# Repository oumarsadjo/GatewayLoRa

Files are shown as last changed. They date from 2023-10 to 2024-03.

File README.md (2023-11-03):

************************************************
************************************************
*** ANNEE: 2023-2024                         ***
*** PROJET: GetwayLoRa                       ***
*** NIVEAU: 4 annee                          ***
*** ECOLE: Polytch Nice Sophia               ***
*** ELEVES: Oumar Sadjo Barry                ***
***         Mor Djeng                        ***
*** PROFESSEUR: Christian Peter              ***
*** DERNIERE MISE AJOUR: 10/27/2023          ***
************************************************
************************************************

********************************************
*** LES ETAPES QUE NOUS AVONS SUIVI SONT ***
********************************************

1. LECTURES DES DIFFERENTES DOCUMENTATIONS
------------------------------------------
Nous avons commencé par lire attentivement toutes les documents (datasheets),
des deux cartes. C'est qui nous a donne une vue générale de leurs fonctionnements.
Nous avons analysé les differents schematics et prendre connaissance de leur brochages.

2. INTERCONNEXION DES DEUX CARTES (CABLAGE)
------------------------------------------
Apres avoir pris connaissance des deux datasheet, nous avons choisi un protocole de
communication UART pour permettre la transmission. Nous avons identifié l'alimentation
des deux cartes qui à 5V chacune.

3. PROTOCOLE ET BROCHAGE
------------------------
Protocole: UART
Connexion: ESP32 ============> SIM7000G
           5V    ------------> V
           GND   ------------> G
           16    ------------> T //RX to TX
           17    ------------> R //TX to RX

4. UTILISATION DE IDE ARDUINO POUR LES TESTS
--------------------------------------------
Nous avons codé une première fonction "void sendCommand(String myCommand)", qui permet
d'envoyer des commandes AT et afficher le resultat au port serial désiré.
NOTE: Toutes les fonctions sont ecrites dans un fichier d'entete (header), nomme "myFonctions.h".

5. LES PREMIERES FONCTIONS
-------------------------
Nous avons ecris une premiere fonction capable d'envoyer un SMS a un numero désiré nommee : 
"void sendMessage(const char* numero, const char* texte)" et une deuxième fonction qui permet de lire
des messages recus nommee: "void readMessage()".

6. FONCTIONS PRINCIPALES
------------------------
A. void myWiFiConnexion(const char* ssid, const char* password): cette fonction nous permet de se connecter un reseau WiFi desire.

B. void sendRequestByWiFi(const char* ssid, const char* password, const String urlServer):
   Cette fonction permet d'envoyer des requettes HTTP GET en utilisant un reseau WiFi dedié. La limite de cette foncttionnalité,
   est que certains endroits où se projet sera utilisé; n'ont pas de WiFi. Pour aller plus loin, on va utiliser le GSM.
  Elle procede comme suit:
   a. Connexion a un reseau WiFi
   b. Verification de la connexion
   c. Initialisation du protocole HTTP
   d. Obtention de la longeur ou de la taille de la page
   e. Affichage du resultat obtenu
   f. Fermeture du protocole HTTP

C. void sendRequestByGSM(const char* url):
   Cette fonction permet d'envoyer des requettes HTTP GET en utilisant le reseau GSM. L'utilisateur precise le serveur ou le lien.
   Elle procede comme suit:
   a. Initialisation du reseau GSM
   b. Obtention d'une IP adress pour communiquer en GSM
   c. Initialisation du protocole HTTP
   d. Obtention de la longeur ou de la taille de la page
   e. Affichage du resultat obtenu
   f. Fermeture du protocole HTTP

7. ETAPES SCHEMATICS
--------------------
C'est cette etape nous devons commencer maintenant.....

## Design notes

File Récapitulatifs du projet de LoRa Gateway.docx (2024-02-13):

Récapitulatifs du projet de LoRa Gateway

1. Objectif du projet :

Développer un système embarqué utilisant une carte ESP32 pour se connecter à Internet via LoRa, en plus des fonctionnalités WiFi et GSM. Ce système doit pouvoir envoyer des requêtes HTTP pour récupérer des données à partir d'une URL spécifique, ainsi que communiquer via LoRa pour envoyer et recevoir des messages et utiliser des fonctionnalités GPS pour obtenir des informations de localisation.

2. Matériels :

Une carte ESP32 avec prise en charge LoRa, un module carte SIM LTE/GSM, un module GPS, une connexion Internet via WiFi (facultative), une carte SIM, et un ordinateur pour la programmation et le téléversement du code Arduino.

3. Fonctionnement du code :

Le code établit des connexions WiFi, GSM et LoRa, envoie des requêtes HTTP pour récupérer des données, envoie et reçoit des SMS via GSM, et utilise des fonctionnalités GPS pour obtenir des informations de localisation. Il est organisé en fonctions modulaires pour différentes tâches. Les tests ont été réalisés avec succès, confirmant le bon fonctionnement du code.

4. Outils utilisés :

L'IDE Arduino pour l'écriture, la compilation et le téléversement du code, la bibliothèque Arduino pour les périphériques ESP32 avec prise en charge LoRa, des bibliothèques tierces pour la communication GSM, et des modules matériels externes tels que le module GPS. GitHub est utilisé pour la gestion de version du code source, et Eagle est utilisé pour le design de la carte.

5. Avancement du projet :

Les tests ont été effectués avec succès, confirmant le bon fonctionnement du code. La phase de conception du schéma de la carte est terminée et le routage avec Eagle a commencé. Cette phase est cruciale pour garantir la fiabilité et les performances du circuit imprimé, en prenant en compte les spécificités de la communication LoRa.

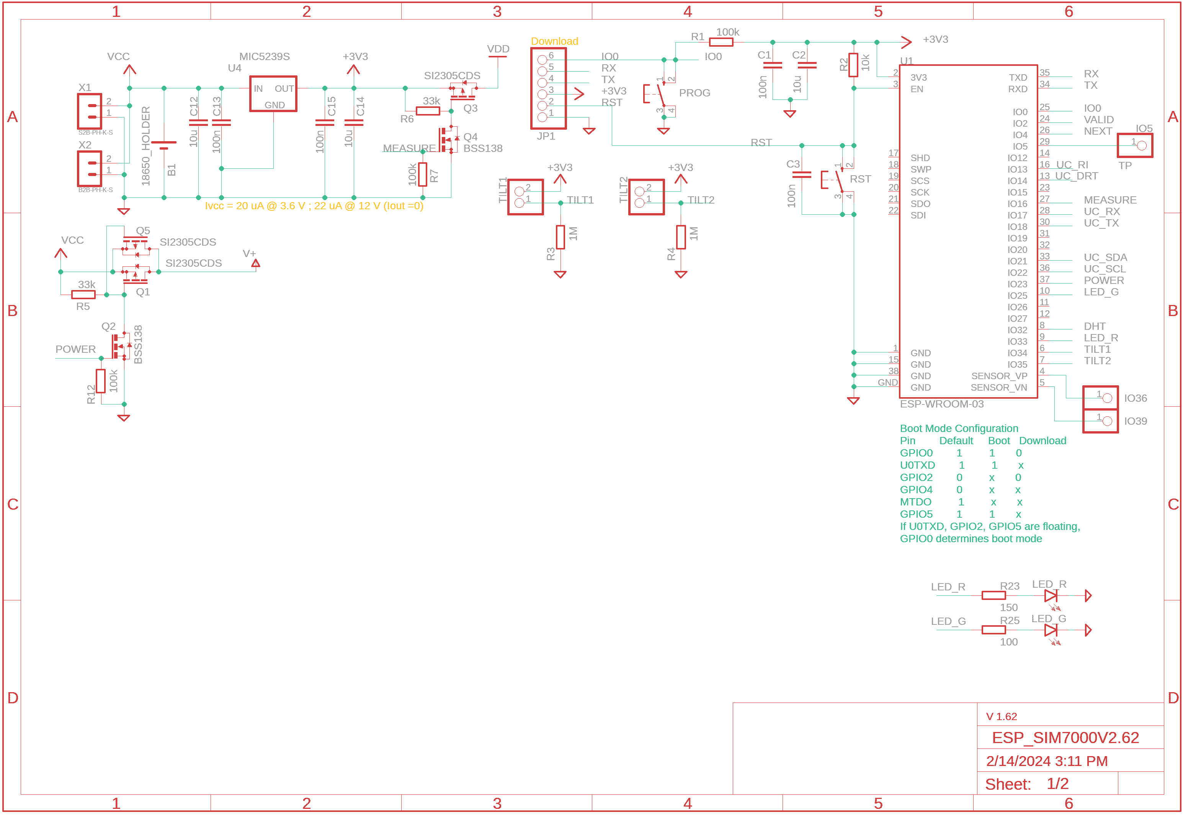
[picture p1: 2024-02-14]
schematic_last_update/Page1.png

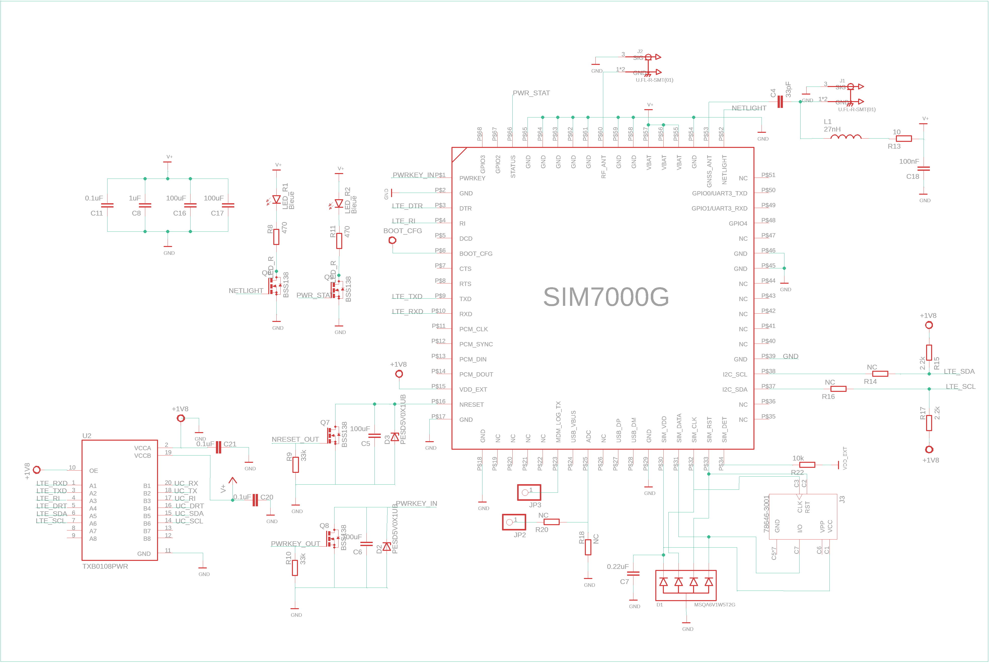
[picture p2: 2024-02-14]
schematic_last_update/Page2.png

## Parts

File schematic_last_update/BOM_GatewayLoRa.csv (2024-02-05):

N� | Type | Part | Value | Device | Package | Needed | Reference | Code commande | SBC | Description | CHECK_PRICES | DESCRIPTION2 | DIGIKEY_PART_NUMBER | MF | MP | MPN | OC_FARNELL | OC_NEWARK | PACKAGE3 | POPULARITY | PRICE | PURCHASE-URL | RS_COMPONENTS_7092778P_PURCHASE_URL | RS_COMPONENTS_7092778_PURCHASE_URL | RS_COMPONENTS_9236790_PURCHASE_URL | SNAPEDA_LINK | SPICEMODEL | SPICEPREFIX | B1 | 18650_HOLDER | C1 | 100n | CC1206 | C1206 | CAPACITOR, European symbol
1 | Diode | D1 | MSQA6V1W5T2G | MSQA6V1W5T2G | SC88A | YES | MSQA6V1W5T2G | 786-2987 | RS | ESD Protection Diode Array Check availability | https://www.snapeda.com/parts/MSQA6V1W5T2G/Onsemi/view-part/?ref=eda | Clamp Ipp Tvs Diode Surface Mount SC-88A (SC-70-5/SOT-353) |  | onsemi | MSQA6V1W5T2G |  |  |  | SC-88A-5 ON Semiconductor |  | None | https://www.snapeda.com/api/url_track_click_mouser/?unipart_id=7122110&manufacturer=onsemi∂_name=MSQA6V1W5T2G&search_term=msqa6v1w5t2g |  |  |  | https://www.snapeda.com/parts/MSQA6V1W5T2G/Onsemi/view-part/?ref=snap
2 | Diode | D2 | PESD5V0X1UB | PESD5V0X1UB | SOD523 | YES | PESD5V0X1UB,135 | 509-386 | RS | Ultra low capacitance unidirectional ElectroStatic Discharge (ESD) protection diode in a | https://www.snapeda.com/parts/PESD5V0X1UB/Nexperia/view-part/?ref=eda | 8V (Typ) Clamp 1.5A (8/20µs) Ipp Tvs Diode Surface Mount SOD-523 |  | Nexperia USA | PESD5V0X1UB |  |  |  | SOD-523 NXP Semiconductors |  | None |  |  |  |  | https://www.snapeda.com/parts/PESD5V0X1UB/Nexperia/view-part/?ref=snap
3 | Diode | D3 | PESD5V0X1UB | PESD5V0X1UB | SOD523 | YES | PESD5V0X1UB,135 | 509-386 | RS | Ultra low capacitance unidirectional ElectroStatic Discharge (ESD) protection diode in a | https://www.snapeda.com/parts/PESD5V0X1UB/Nexperia/view-part/?ref=eda | 8V (Typ) Clamp 1.5A (8/20µs) Ipp Tvs Diode Surface Mount SOD-523 |  | Nexperia USA | PESD5V0X1UB |  |  |  | SOD-523 NXP Semiconductors |  | None |  |  |  |  | https://www.snapeda.com/parts/PESD5V0X1UB/Nexperia/view-part/?ref=snap
4 | Inductor | L1 | 27nH | LQM21PN1R0NGRD | LQM21PN1R0NGRD | YES | 7447880127 | 238-9575 | RS
5 | Registor | R13 | 10 | RR1206 | R1206 | YES |  | 812-1782 | RS | RESISTOR, European symbol |  |  |  |  |  |  |  |  |  |  |  |  |  |  |  |  | NONE | R
6 | Regulator | U3 | TXB0104D | TXB0104D | SOIC127P600X175-14N | YES | TXB0104D | 709-2778 | RS |  | https://www.snapeda.com/parts/TXB0104D/Texas+Instruments/view-part/?ref=eda | 4-Bit Bidirectional Voltage-Level Shifter with Auto Direction Sensing and +/-15 kV ESD Protect |  | Texas Instruments | TXB0104D |  |  |  | SOIC-14 Texas Instruments |  |  | https://www.snapeda.com/api/url_track_click_mouser/?unipart_id=44550&manufacturer=Texas Instruments∂_name=TXB0104D&search_term=txb0104 | https://www.snapeda.com/api/url_track_click/https%253A//uk.rs-online.com/web/p/translator-ics/7092778p//%253Futm_campaign%253Dbuynow%2526utm_medium%253Daggreg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 Instruments∂_name=TXB0104D&search_term=txb0104 | https://www.snapeda.com/api/url_track_click/https%253A//uk.rs-online.com/web/p/translator-ics/7092778//%253Futm_campaign%253Dbuynow%2526utm_medium%253Daggrega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 Instruments∂_name=TXB0104D&search_term=txb0104 | https://www.snapeda.com/api/url_track_click/https%253A//uk.rs-online.com/web/p/translator-ics/9236790//%253Futm_campaign%253Dbuynow%2526utm_medium%253Daggrega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 Instruments∂_name=TXB0104D&search_term=txb0104 | https://www.snapeda.com/parts/TXB0104D/Texas+Instruments/view-part/?ref=snap
7 | SIM | U$2 | 78646-3001 | Micro SIM | 78646-3001 | YES | 78646-3001 | 896-7487 | RS
8 | Capacitor | C1 | 100n | CC1206 | C1206 | Available |  |  | RS | CAPACITOR, European symbol |  |  |  |  |  |  |  |  |  |  |  |  |  |  |  |  | NONE | C
9 | Capacitor | C10 | 0.1uF | CC1210 | C1210 | Available |  |  | RS | CAPACITOR, European symbol |  |  |  |  |  |  |  |  |  |  |  |  |  |  |  |  | NONE | C
10 | Capacitor | C11 | 0.1uF | C-EUC0805 | C0805 | Available |  |  | RS | CAPACITOR, European symbol |  |  |  |  |  |  |  |  |  | 88 |  |  |  |  |  |  |  | C
11 | Capacitor | C12 | 10u | CC1210 | C1210 | Available |  |  | RS | CAPACITOR, European symbol |  |  |  |  |  |  |  |  |  |  |  |  |  |  |  |  | NONE | C
12 | Capacitor | C13 | 100n | CC1206 | C1206 | Available |  |  | RS | CAPACITOR, European symbol |  |  |  |  |  |  |  |  |  |  |  |  |  |  |  |  | NONE | C
13 | Capacitor | C14 | 10u | CC1210 | C1210 | Available |  |  | RS | CAPACITOR, European symbol |  |  |  |  |  |  |  |  |  |  |  |  |  |  |  |  | NONE | C
14 | Capacitor | C15 | 100n | CC1206 | C1206 | Available |  |  | RS | CAPACITOR, European symbol |  |  |  |  |  |  |  |  |  |  |  |  |  |  |  |  | NONE | C
15 | Capacitor | C16 | 100uF | C-EUC0805 | C0805 | Available |  |  | RS | CAPACITOR, European symbol |  |  |  |  |  |  |  |  |  | 88 |  |  |  |  |  |  |  | C
16 | Capacitor | C17 | 100uF | C-EUC0805 | C0805 | Available |  |  | RS | CAPACITOR, European symbol |  |  |  |  |  |  |  |  |  | 88 |  |  |  |  |  |  |  | C
17 | Capacitor | C18 | 100nF | C-EUC0805 | C0805 | Available |  |  | RS | CAPACITOR, European symbol |  |  |  |  |  |  |  |  |  | 88 |  |  |  |  |  |  |  | C
18 | Capacitor | C2 | 10u | CC1210 | C1210 | Available |  |  | RS | CAPACITOR, European symbol |  |  |  |  |  |  |  |  |  |  |  |  |  |  |  |  | NONE | C
19 | Capacitor | C3 | 100n | CC1206 | C1206 | Available |  |  | RS | CAPACITOR, European symbol |  |  |  |  |  |  |  |  |  |  |  |  |  |  |  |  | NONE | C
20 | Capacitor | C4 | 33pF | C-EUC0805 | C0805 | Available |  |  | RS | CAPACITOR, European symbol |  |  |  |  |  |  |  |  |  | 88 |  |  |  |  |  |  |  | C
21 | Capacitor | C5 | 100uF | C-EUC0805 | C0805 | Available |  |  | RS | CAPACITOR, European symbol |  |  |  |  |  |  |  |  |  | 88 |  |  |  |  |  |  |  | C
22 | Capacitor | C6 | 100uF | C-EUC0805 | C0805 | Available |  |  | RS | CAPACITOR, European symbol |  |  |  |  |  |  |  |  |  | 88 |  |  |  |  |  |  |  | C
23 | Capacitor | C7 | 0.22uF | C-EUC0805 | C0805 | Available |  |  | RS | CAPACITOR, European symbol |  |  |  |  |  |  |  |  |  | 88 |  |  |  |  |  |  |  | C
24 | Capacitor | C8 | 1uF | C-EUC0805 | C0805 | Available |  |  | RS | CAPACITOR, European symbol |  |  |  |  |  |  |  |  |  | 88 |  |  |  |  |  |  |  | C
25 | Capacitor | C9 | 0.1uF | CC1210 | C1210 | Available |  |  | RS | CAPACITOR, European symbol |  |  |  |  |  |  |  |  |  |  |  |  |  |  |  |  | NONE | C
26 | Connector | IO36 |  | PINHD-1X1 | 1X01 | Available |  |  | RS | PIN HEADER |  |  |  |  |  |  |  |  |  | 64
27 | Connector | IO39 |  | PINHD-1X1 | 1X01 | Available |  |  | RS | PIN HEADER |  |  |  |  |  |  |  |  |  | 64
28 | Connector | IO5 | TP | PINHD-1X1 | 1X01 | Available |  |  | RS | PIN HEADER |  |  |  |  |  |  |  |  |  | 64
29 | Connector | TILT1 |  | PINHD-1X2 | 1X02 | Available |  |  | RS | PIN HEADER |  |  |  |  |  |  |  |  |  | 98
30 | Connector | TILT2 |  | PINHD-1X2 | 1X02 | Available |  |  | RS | PIN HEADER |  |  |  |  |  |  |  |  |  | 98
31 | IC | U$1 | SIM7000G | SIM7000G | SIM7000G | Available |  |  | RS |  | https://www.snapeda.com/parts/SIM7000G/SIMCom/view-part/?ref=eda | 802.15.4 Cat-M, Cat-NB, EDGE, GPRS, LPWA Transceiver Module 850MHz, 900MHz, 1.8GHz, 1.9GHz Antenna Not Included Surface Mount |  | SIMCom Wireless Solutions Limited | SIM7000G |  |  |  | None |  |  | https://www.snapeda.com/api/url_track_click_mouser/?unipart_id=12130268&manufacturer=SIMCom Wireless Solutions Limited∂_name=SIM7000G&search_term=sim7000g |  |  |  | https://www.snapeda.com/parts/SIM7000G/SIMCom/view-part/?ref=snap
32 | Interupteur | PROG |  | 10-XX | B3F-10XX | Available |  |  | RS | OMRON SWITCH |  |  |  |  |  | B3F-1000 | 176432 | 36M3542 |  | 72
33 | Interupteur | RST |  | 10-XX | B3F-10XX | Available |  |  | RS | OMRON SWITCH |  |  |  |  |  | B3F-1000 | 176432 | 36M3542 |  | 72
34 | LED | LED_G |  | LEDSMT1206 | 1206 | Available |  |  | RS | LED |  |  |  |  |  |  |  |  |  | 20
35 | LED | LED_R |  | LEDSMT1206 | 1206 | Available |  |  | RS | LED |  |  |  |  |  |  |  |  |  | 20
36 | LED | LED_R1 | Bleue | LEDSMT1206 | 1206 | Available |  |  | RS | LED |  |  |  |  |  |  |  |  |  | 20
37 | LED | LED_R2 | Bleue | LEDSMT1206 | 1206 | Available |  |  | RS | LED |  |  |  |  |  |  |  |  |  | 20
38 | Microcontroller | U1 | ESP-WROOM-03 | ESP-WROOM-03 | ESP-WROOM-03 | Available |  |  | RS |  |  |  |  |  |  |  | unknown
39 | Pin Header | JP1 |  | PINHD-1X6 | 1X06 | Available |  |  | RS | PIN HEADER |  |  |  |  |  |  |  |  |  | 79
40 | Pin Header | X1 | S2B-PH-K-S | S2B-PH-K-S | S2B-PH-K-S | Available |  |  | RS | JST PH series header 2.00mm pitch disconnectable crimp style connectors, horizontal (side entry type), 2 pins
41 | Pin Header | X2 | B2B-PH-K-S | B2B-PH-K-S | B2B-PH-K-S | Available |  |  | RS | JST PH series header 2.00mm pitch disconnectable crimp style connectors, vertical (side entry type), 2 pins
42 | Registor | R1 | 100k | RR1206 | R1206 | Available |  |  | RS | RESISTOR, European symbol |  |  |  |  |  |  |  |  |  |  |  |  |  |  |  |  | NONE | R
43 | Registor | R10 | 33k | RR1206 | R1206 | Available |  |  | RS | RESISTOR, European symbol |  |  |  |  |  |  |  |  |  |  |  |  |  |  |  |  | NONE | R
44 | Registor | R11 | 470 | RR1206 | R1206 | Available |  |  | RS | RESISTOR, European symbol |  |  |  |  |  |  |  |  |  |  |  |  |  |  |  |  | NONE | R
45 | Registor | R12 | 100k | RR1206 | R1206 | Available |  |  | RS | RESISTOR, European symbol |  |  |  |  |  |  |  |  |  |  |  |  |  |  |  |  | NONE | R
46 | Registor | R14 | NC | RR1206 | R1206 | Available |  |  | RS | RESISTOR, European symbol |  |  |  |  |  |  |  |  |  |  |  |  |  |  |  |  | NONE | R
47 | Registor | R15 | 2.2k | RR1206 | R1206 | Available |  |  | RS | RESISTOR, European symbol |  |  |  |  |  |  |  |  |  |  |  |  |  |  |  |  | NONE | R
48 | Registor | R16 | NC | RR1206 | R1206 | Available |  |  | RS | RESISTOR, European symbol |  |  |  |  |  |  |  |  |  |  |  |  |  |  |  |  | NONE | R
49 | Registor | R17 | 2.2k | RR1206 | R1206 | Available |  |  | RS | RESISTOR, European symbol |  |  |  |  |  |  |  |  |  |  |  |  |  |  |  |  | NONE | R
50 | Registor | R2 | 10k | RR1206 | R1206 | Available |  |  | RS | RESISTOR, European symbol |  |  |  |  |  |  |  |  |  |  |  |  |  |  |  |  | NONE | R
51 | Registor | R23 | 150 | RR1206 | R1206 | Available |  |  | RS | RESISTOR, European symbol |  |  |  |  |  |  |  |  |  |  |  |  |  |  |  |  | NONE | R
52 | Registor | R25 | 100 | RR1206 | R1206 | Available |  |  | RS | RESISTOR, European symbol |  |  |  |  |  |  |  |  |  |  |  |  |  |  |  |  | NONE | R
53 | Registor | R3 | 1M | RR1206 | R1206 | Available |  |  | RS | RESISTOR, European symbol |  |  |  |  |  |  |  |  |  |  |  |  |  |  |  |  | NONE | R
54 | Registor | R4 | 1M | RR1206 | R1206 | Available |  |  | RS | RESISTOR, European symbol |  |  |  |  |  |  |  |  |  |  |  |  |  |  |  |  | NONE | R
55 | Registor | R5 | 33k | RR1206 | R1206 | Available |  |  | RS | RESISTOR, European symbol |  |  |  |  |  |  |  |  |  |  |  |  |  |  |  |  | NONE | R
56 | Registor | R6 | 33k | RR1206 | R1206 | Available |  |  | RS | RESISTOR, European symbol |  |  |  |  |  |  |  |  |  |  |  |  |  |  |  |  | NONE | R
57 | Registor | R7 | 100k | RR1206 | R1206 | Available |  |  | RS | RESISTOR, European symbol |  |  |  |  |  |  |  |  |  |  |  |  |  |  |  |  | NONE | R
58 | Registor | R8 | 470 | RR1206 | R1206 | Available |  |  | RS | RESISTOR, European symbol |  |  |  |  |  |  |  |  |  |  |  |  |  |  |  |  | NONE | R
59 | Registor | R9 | 33k | RR1206 | R1206 | Available |  |  | RS | RESISTOR, European symbol |  |  |  |  |  |  |  |  |  |  |  |  |  |  |  |  | NONE | R
60 | Regulator | U4 | MIC5239S | MIC5239S | SOT223 | Available |  |  | RS | LDO REGULATOR
61 | Transistor | Q1 | SI2305CDS | SI2305CDS | SOT23 | Available |  |  | RS | P-CHANNEL MOS FET
62 | Transistor | Q2 | BSS138 | BSS131 | SOT23 | Available |  |  | RS | N-CHANNEL MOS FET
63 | Transistor | Q3 | SI2305CDS | SI2305CDS | SOT23 | Available |  |  | RS | P-CHANNEL MOS FET
64 | Transistor | Q4 | BSS131 | BSS131 | SOT23 | Available |  |  | RS | N-CHANNEL MOS FET
65 | Transistor | Q5 | SI2305CDS | SI2305CDS | SOT23 | Available |  |  | RS | P-CHANNEL MOS FET
66 | Transistor | Q6 | BSS138 | BSS131 | SOT23 | Available |  |  | RS | N-CHANNEL MOS FET
67 | Transistor | Q7 | BSS138 | BSS131 | SOT23 | Available |  |  | RS | N-CHANNEL MOS FET
68 | Transistor | Q8 | BSS138 | BSS131 | SOT23 | Available |  |  | RS | N-CHANNEL MOS FET
69 | Transistor | Q9 | BSS138 | BSS131 | SOT23 | Available |  |  | RS | N-CHANNEL MOS FET
70 | UFL | J1 | U.FL-R-SMT(01) | U.FL-R-SMT(01) | HRS_U.FL-R-SMT(01) | Available |  |  | RS | U.FL Series 6 Ghz 50 Ohm Ultra-small SMT Coaxial Cable Receptacle Check availability | https://www.snapeda.com/parts/U.FL-R-SMT(01)/Hirose+Electric+Co+Ltd/view-part/?ref=eda | U.FL (UMCC) Connector Receptacle, Male Pin 50Ohm Surface Mount Solder. RF Connectors / Coaxial Connectors |  | Hirose | U.FL-R-SMT(01) |  |  |  | None |  | None | https://www.snapeda.com/api/url_track_click_mouser/?unipart_id=49572&manufacturer=Hirose∂_name=U.FL-R-SMT(01)&search_term=None |  |  |  | https://www.snapeda.com/parts/U.FL-R-SMT(01)/Hirose+Electric+Co+Ltd/view-part/?ref=snap
71 | UFL | J2 | U.FL-R-SMT(01) | U.FL-R-SMT(01) | HRS_U.FL-R-SMT(01) | Available |  |  | RS | U.FL Series 6 Ghz 50 Ohm Ultra-small SMT Coaxial Cable Receptacle Check availability | https://www.snapeda.com/parts/U.FL-R-SMT(01)/Hirose+Electric+Co+Ltd/view-part/?ref=eda | U.FL (UMCC) Connector Receptacle, Male Pin 50Ohm Surface Mount Solder. RF Connectors / Coaxial Connectors |  | Hirose | U.FL-R-SMT(01) |  |  |  | None |  | None | https://www.snapeda.com/api/url_track_click_mouser/?unipart_id=49572&manufacturer=Hirose∂_name=U.FL-R-SMT(01)&search_term=None |  |  |  | https://www.snapeda.com/parts/U.FL-R-SMT(01)/Hirose+Electric+Co+Ltd/view-part/?ref=snap
72 |  | B1 | 18650_HOLDER | 18650_HOLDER | 18650 | Available |  |  | RS | 18650 holder
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

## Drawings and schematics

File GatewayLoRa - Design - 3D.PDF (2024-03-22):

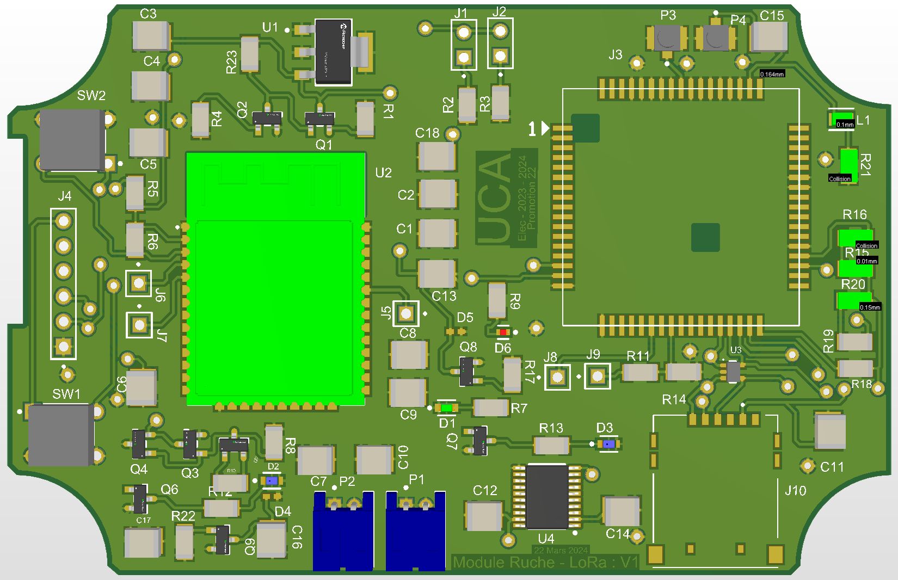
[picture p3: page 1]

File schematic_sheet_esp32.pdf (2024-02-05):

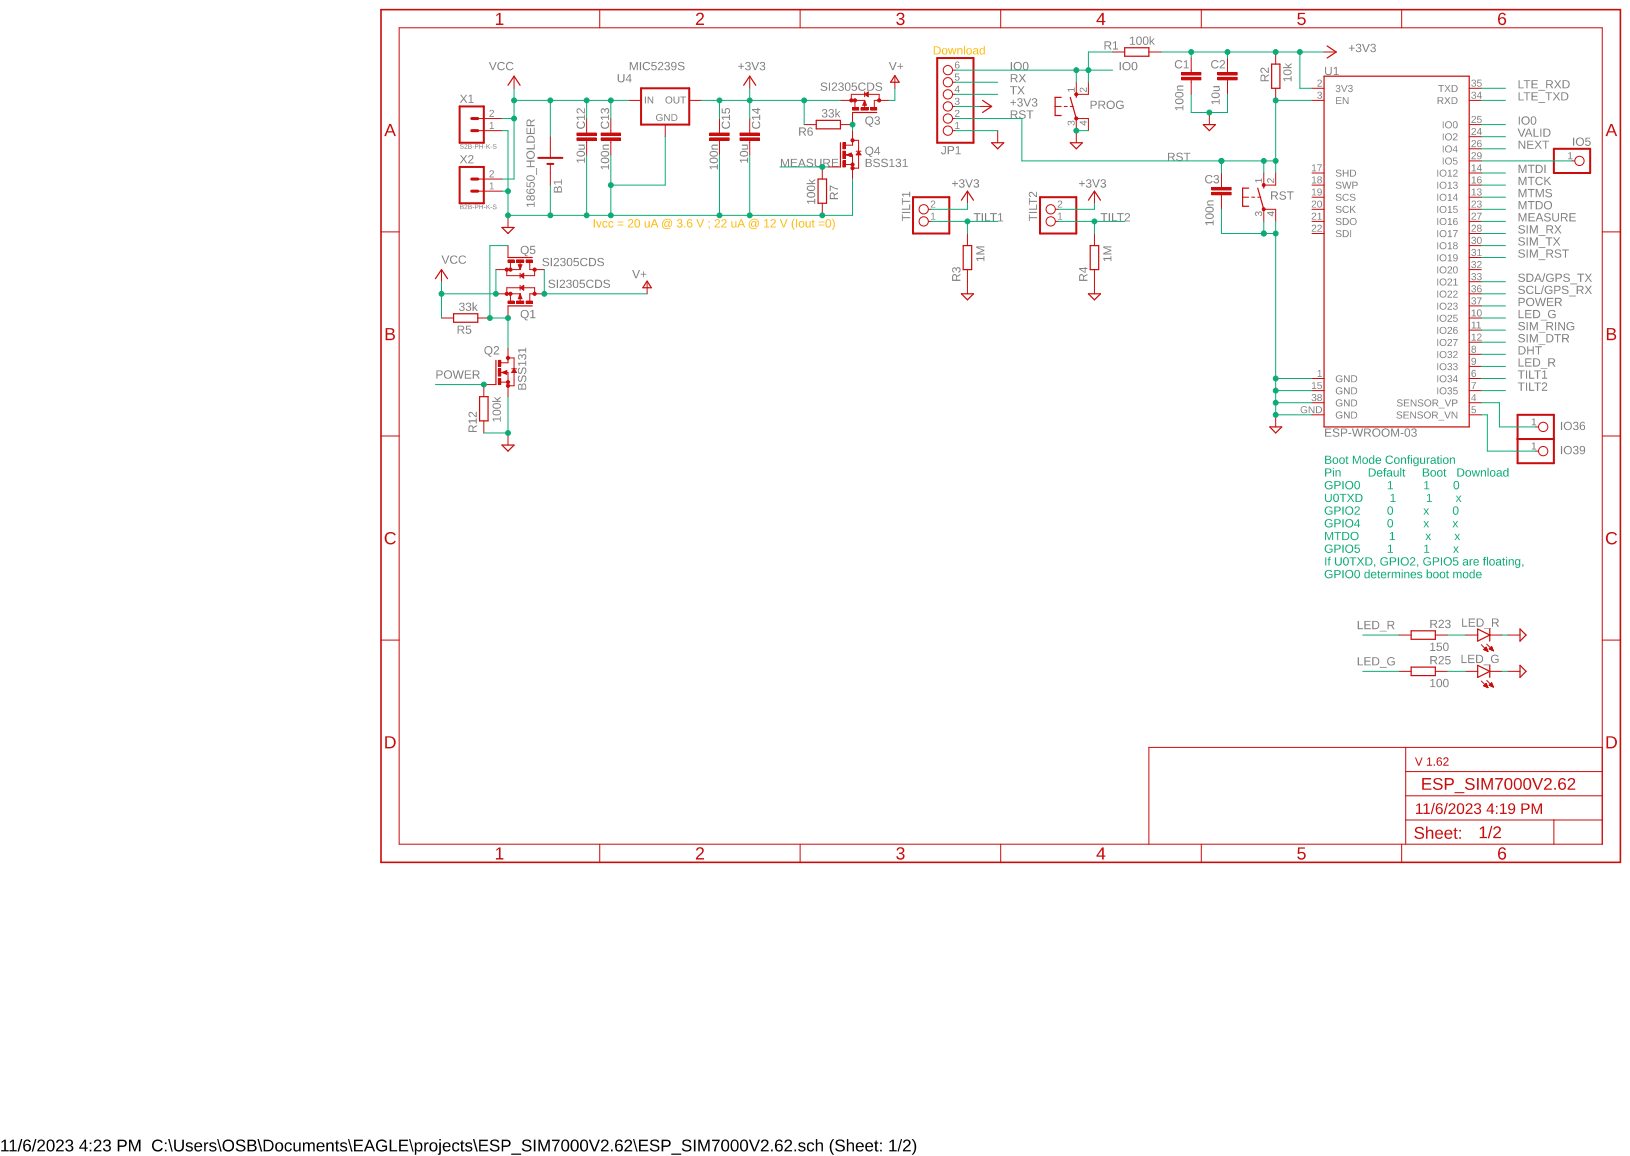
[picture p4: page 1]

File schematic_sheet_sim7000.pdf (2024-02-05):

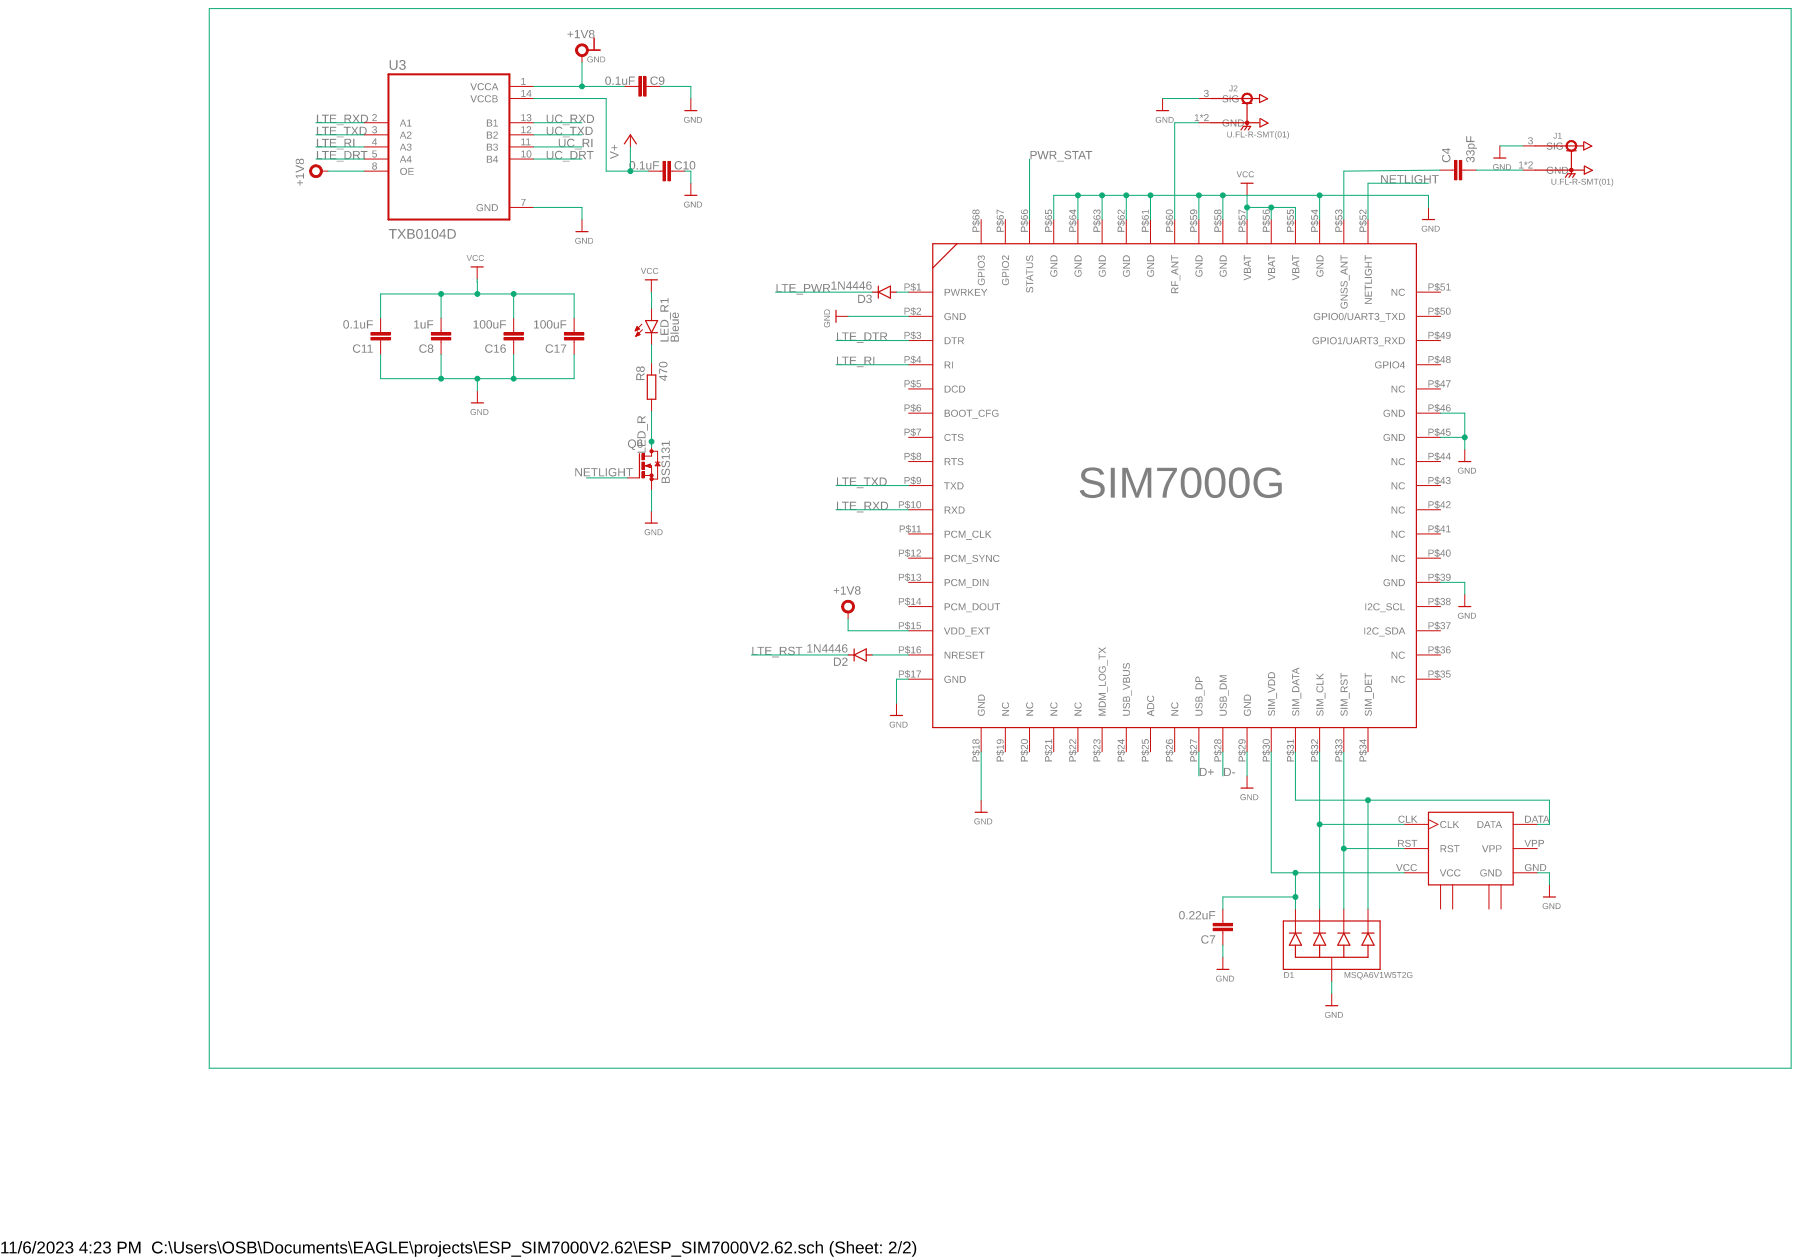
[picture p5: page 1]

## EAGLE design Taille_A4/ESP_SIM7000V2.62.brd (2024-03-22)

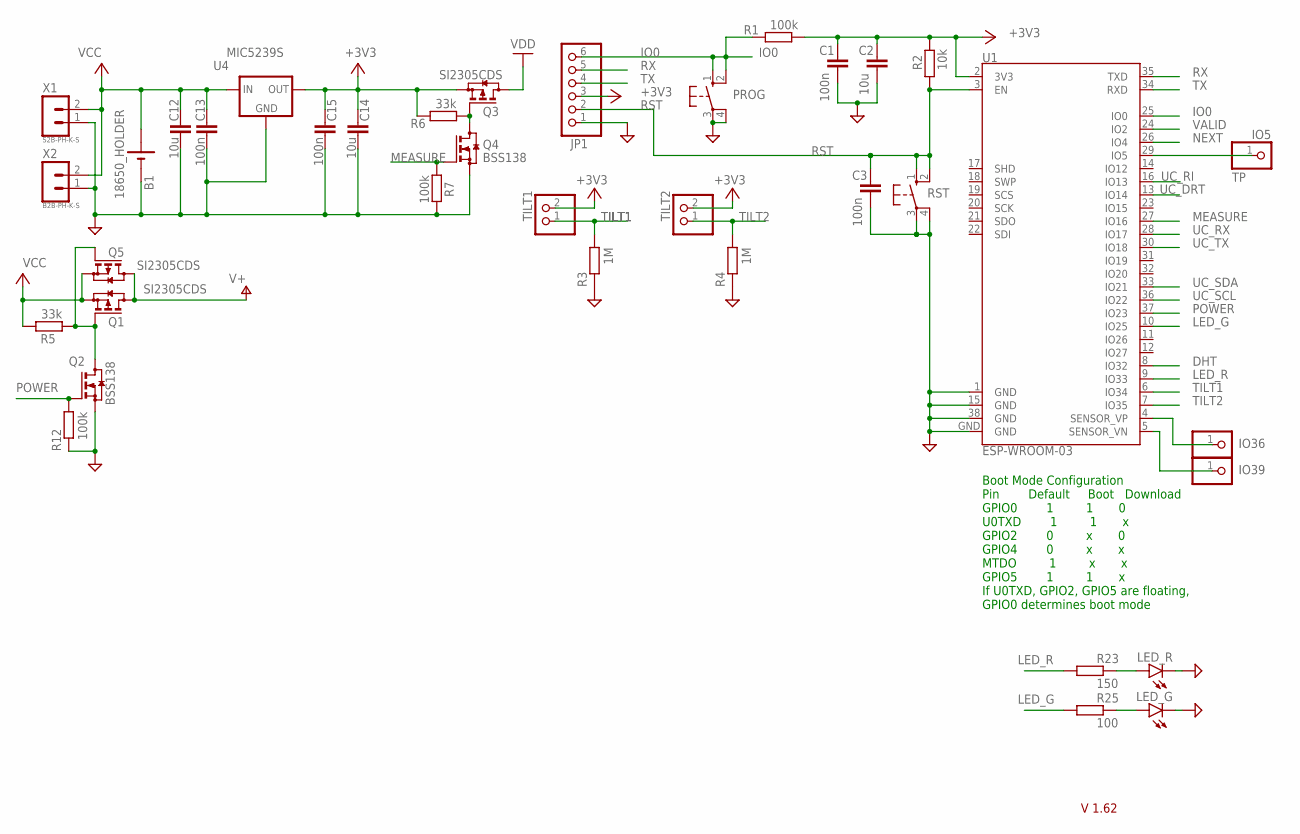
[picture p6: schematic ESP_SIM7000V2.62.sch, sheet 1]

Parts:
B1: 18650_HOLDER; 18650
C1, C3, C13, C15: 100n; C1206
C2, C12, C14: 10u; C1210
IO5: TP; 1X01
IO36, IO39: PINHD-1X1; 1X01
JP1: PINHD-1X6; 1X06
LED_G: LEDSMT1206; 1206
LED_R: LEDSMT1206; 1206
PROG: 10-XX; B3F-10XX
Q1, Q3, Q5: SI2305CDS; SOT23
Q2, Q4: BSS138; SOT23
R1, R7, R12: 100k; R1206
R2: 10k; R1206
R3, R4: 1M; R1206
R5, R6: 33k; R1206
R23: 150; R1206
R25: 100; R1206
RST: 10-XX; B3F-10XX
TILT1, TILT2: PINHD-1X2; 1X02
U1: ESP-WROOM-03
U4: MIC5239S; SOT223
X1: S2B-PH-K-S
X2: B2B-PH-K-S

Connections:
+3V3: C1.1, C2.1, C14.1, C15.1, JP1.3, Q3.2 (S), R1.1, R2.2, R6.2, TILT1.2, TILT2.2, U1.2 (3V3), U4.3 (OUT)
DHT: U1.8 (IO32)
GND: B1.-, C1.2, C2.2, C3.2, C12.2, C13.2, C14.2, C15.2, JP1.1, LED_G.C, LED_R.C, PROG.3, PROG.4 (P1), Q2.2 (S), Q4.2 (S), R3.2, R4.2, R7.2, R12.2, RST.3, RST.4 (P1), U1.1 (GND), U1.15 (GND), U1.38 (GND), U1.GND, U4.2 (GND), U4.4 (GND), X1.1, X2.1; also elsewhere on the board
IO0: JP1.6, PROG.1 (S), PROG.2 (S1), R1.2, U1.25 (IO0)
IO36: IO36.1, U1.4 (SENSOR_VP)
IO39: IO39.1, U1.5 (SENSOR_VN)
LED_G: R25.1, U1.10 (IO25)
LED_R: R23.1, U1.9 (IO33); also elsewhere on the board
MEASURE: Q4.1 (G), R7.1, U1.27 (IO16)
unnamed: Q1.1 (G), Q2.3 (D), Q5.1 (G), R5.1
unnamed: Q3.1 (G), Q4.3 (D), R6.1
unnamed: LED_R.A, R23.2
unnamed: LED_G.A, R25.2
unnamed: IO5.1, U1.29 (IO5)
NEXT: U1.26 (IO4)
POWER: Q2.1 (G), R12.1, U1.37 (IO23)
RST: C3.1, JP1.2, R2.1, RST.1 (S), RST.2 (S1), U1.3 (EN)
RX: JP1.5, U1.35 (TXD)
TILT1: R3.1, TILT1.1, U1.6 (IO34)
TILT2: R4.1, TILT2.1, U1.7 (IO35)
TX: JP1.4, U1.34 (RXD)
UC_DRT: U1.13 (IO14); also elsewhere on the board
UC_RI: U1.16 (IO13); also elsewhere on the board
UC_RX: U1.28 (IO17); also elsewhere on the board
UC_SCL: U1.36 (IO22); also elsewhere on the board
UC_SDA: U1.33 (IO21); also elsewhere on the board
UC_TX: U1.30 (IO18); also elsewhere on the board
V+: Q1.3 (D), Q5.3 (D)
VALID: U1.24 (IO2)
VCC: B1.+, C12.1, C13.1, Q1.2 (S), Q5.2 (S), R5.2, U4.1 (IN), X1.2, X2.2
VDD: Q3.3 (D)

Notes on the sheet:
Boot Mode Configuration Pin Default Boot Download GPIO0 1 1 0 U0TXD 1 1 x GPIO2 0 x 0 GPIO4 0 x x MTDO 1 x x GPIO5 1 1 x If U0TXD, GPIO2, GPIO5 are floating, GPIO0 determines boot mode
V 1.62

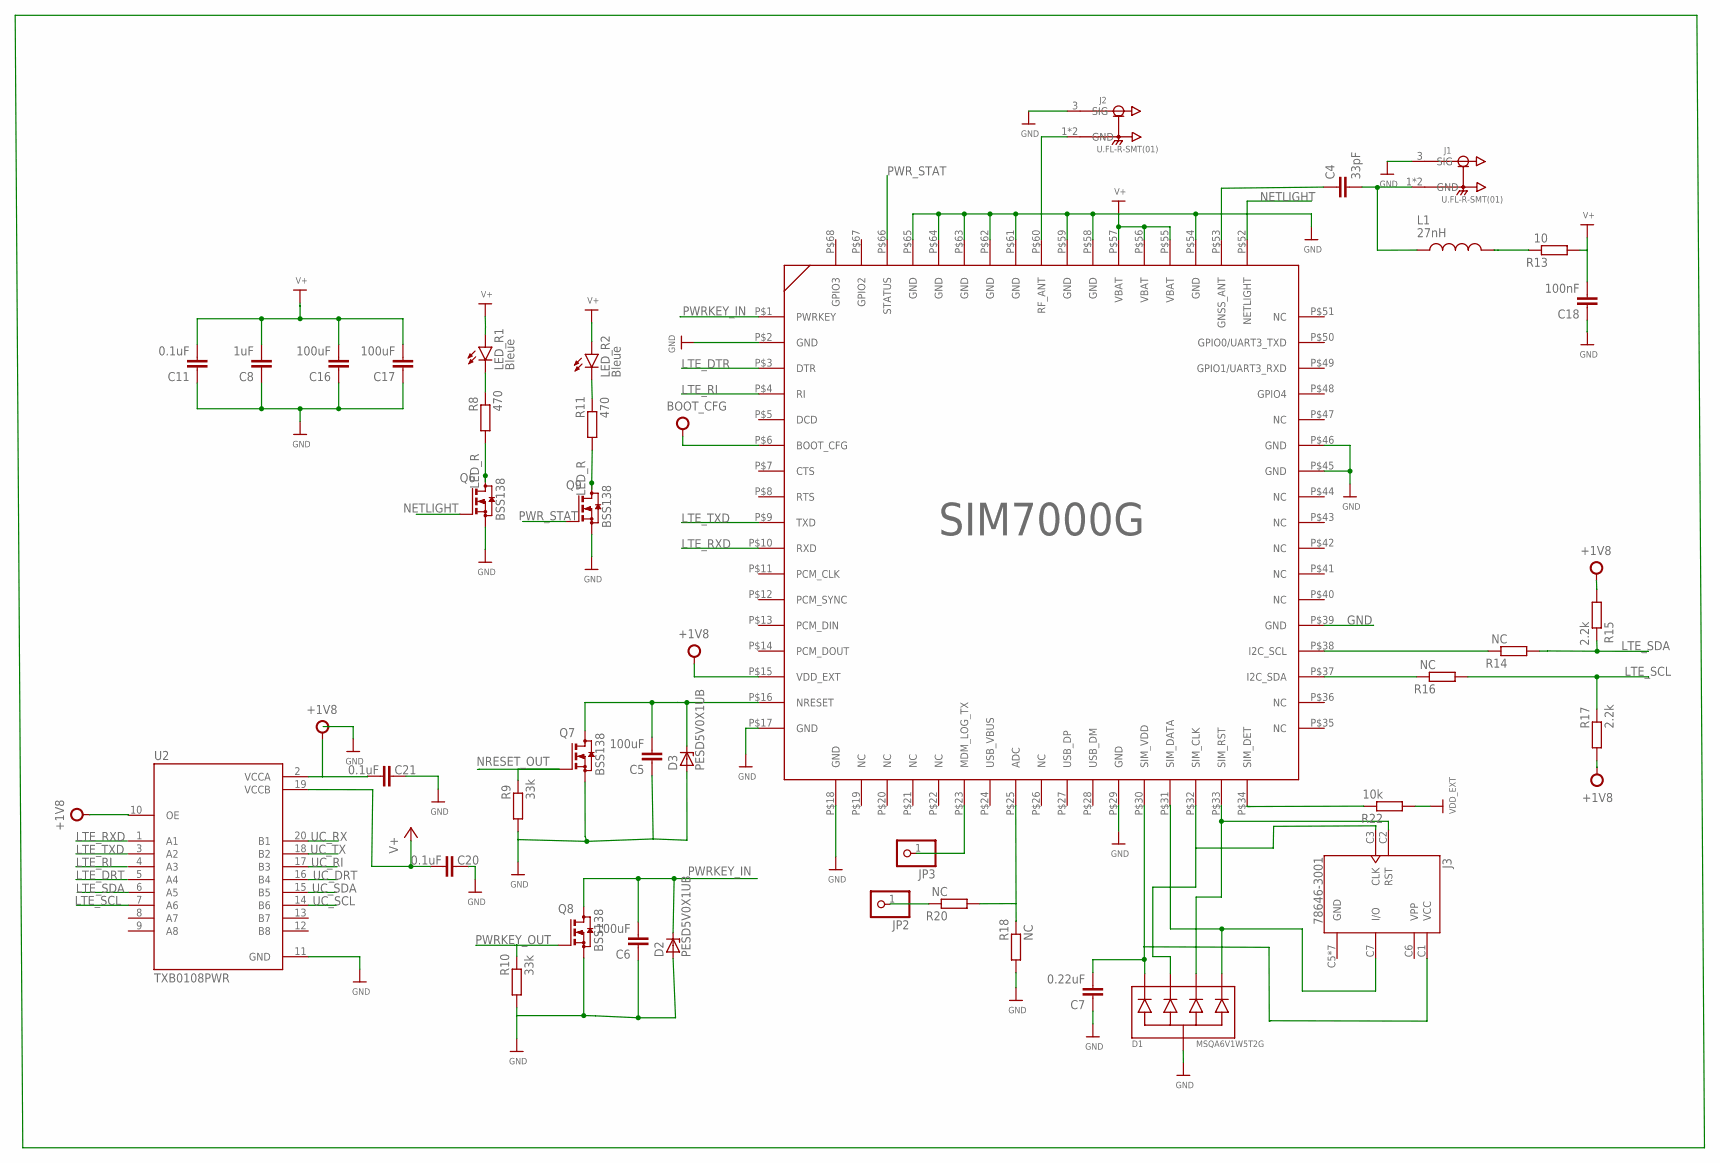
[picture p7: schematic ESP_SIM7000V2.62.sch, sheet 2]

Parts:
C4: 33pF; C0805
C5, C6, C16, C17: 100uF; C0805
C7: 0.22uF; C0805
C8: 1uF; C0805
C11: 0.1uF; C0805
C18: 100nF; C0805
C20, C21: 0.1uF; C1210
D1: MSQA6V1W5T2G; SC88A
D2, D3: PESD5V0X1UB; SOD523
J1, J2: U.FL-R-SMT(01); HRS_U.FL-R-SMT(01)
J3: 78646-3001; MOLEX_78646-3001
JP2, JP3: PINHD-1X1; 1X01
L1: 27nH; INDC2012X100N
LED_R1, LED_R2: Bleue; 1206
Q6, Q7, Q8, Q9: BSS138; SOT23
R8, R11: 470; R1206
R9, R10: 33k; R1206
R13: 10; R1206
R14, R16, R18, R20: NC; R1206
R15, R17: 2.2k; R1206
R22: 10k; R1206
U2: TXB0108PWR; SOP65P640X120-20N
U$1: SIM7000G

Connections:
+1V8: C21.2, R15.1, R17.1, U2.2 (VCCA), U2.10 (OE), U$1.P$6 (BOOT_CFG), U$1.P$15 (VDD_EXT)
+5V: C20.2, U2.19 (VCCB)
GND: C7.1, C8.1, C11.1, C16.1, C17.1, C18.1, C20.1, C21.1, D1.2, J1.3 (SIG), J2.3 (SIG), J3.C5 (GND), J3.G1 (GND), J3.G2 (GND), J3.G3 (GND), J3.G4 (GND), J3.G5 (GND), J3.G6 (GND), LED_R2.A, Q6.2 (S), Q9.2 (S), R18.1, R22.1, U2.11 (GND), U$1.P$2 (GND), U$1.P$17 (GND), U$1.P$18 (GND), U$1.P$29 (GND), U$1.P$39 (GND), U$1.P$45 (GND), U$1.P$46 (GND), U$1.P$54 (GND), U$1.P$55 (VBAT), U$1.P$56 (VBAT), U$1.P$57 (VBAT), U$1.P$58 (GND), U$1.P$59 (GND), U$1.P$61 (GND), U$1.P$62 (GND), U$1.P$63 (GND), U$1.P$64 (GND), U$1.P$65 (GND); also elsewhere on the board
LED_R: Q6.3 (D), Q9.3 (D), R8.1, R11.1; also elsewhere on the board
LTE_DTR: U$1.P$3 (DTR)
LTE_RI: U$1.P$4 (RI)
LTE_RXD: U$1.P$10 (RXD)
LTE_SCL: R16.1, R17.2, U2.7 (A6)
LTE_SDA: R14.1, R15.2, U2.6 (A5)
LTE_TXD: U$1.P$9 (TXD)
unnamed: J2.1 (GND), J2.2 (GND), U$1.P$60 (RF_ANT)
unnamed: C4.2, J1.1 (GND), J1.2 (GND), L1.1
unnamed: C4.1, U$1.P$53 (GNSS_ANT)
unnamed: C5.2, D3.1 (K), Q7.3 (D), U$1.P$16 (NRESET)
unnamed: LED_R1.C, R8.2
unnamed: D1.5, J3.C7 (I/O), U$1.P$31 (SIM_DATA)
unnamed: D1.4, J3.C2 (RST), U$1.P$33 (SIM_RST)
unnamed: C8.2, C11.2, C16.2, C17.2
unnamed: C5.1, D3.2 (A), Q7.2 (S), R9.1
unnamed: C6.1, D2.2 (A), Q8.2 (S), R10.1
unnamed: LED_R2.C, R11.2
unnamed: C18.2, R13.1
unnamed: L1.2, R13.2
unnamed: D1.3, U$1.P$32 (SIM_CLK)
unnamed: R14.2, U$1.P$38 (I2C_SCL)
unnamed: R16.2, U$1.P$37 (I2C_SDA)
unnamed: C7.2, D1.1, U$1.P$30 (SIM_VDD)
unnamed: R18.2, U$1.P$25 (ADC)
unnamed: JP3.1, U$1.P$23 (MDM_LOG_TX)
NETLIGHT: Q6.1 (G), U$1.P$52 (NETLIGHT)
NRESET_OUT: Q7.1 (G), R9.2
PWRKEY_IN: C6.2, Q8.3 (D), U$1.P$1 (PWRKEY)
PWRKEY_OUT: Q8.1 (G)
PWR_STAT: Q9.1 (G), U$1.P$66 (STATUS)
UC_DRT: U2.16 (B4); also elsewhere on the board
UC_RI: U2.17 (B3); also elsewhere on the board
UC_RX: U2.20 (B1); also elsewhere on the board
UC_SCL: U2.14 (B6); also elsewhere on the board
UC_SDA: U2.15 (B5); also elsewhere on the board
UC_TX: U2.18 (B2); also elsewhere on the board
VPP: J3.C6 (VPP)

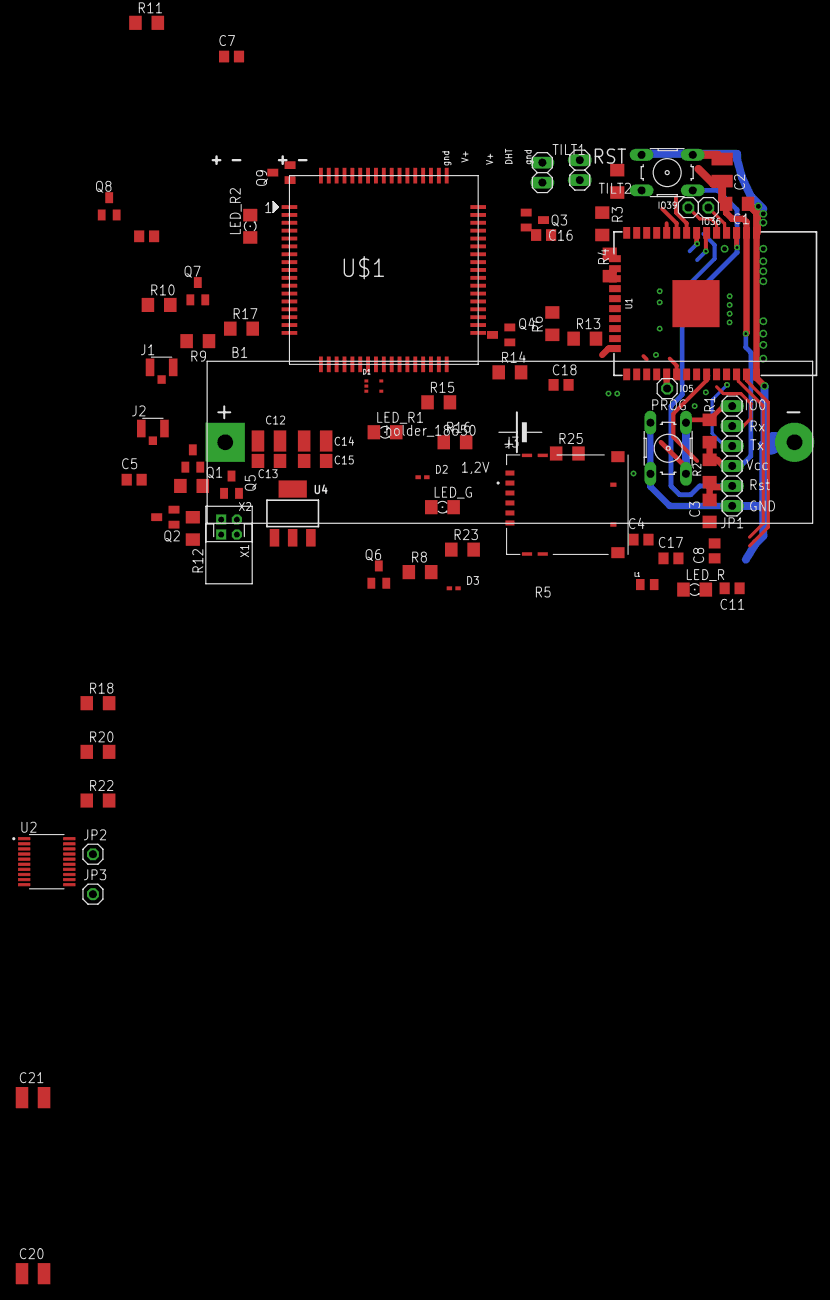
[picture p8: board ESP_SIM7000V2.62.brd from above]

Board: 2 copper layers, 77 parts (0 on the bottom side), 54 nets.

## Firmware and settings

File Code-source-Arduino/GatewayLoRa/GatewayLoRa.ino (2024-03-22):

#include "myFonctions.h"

void setup() {
  Serial.begin(9600);
  //DEMONSTRATION
  //1. Envoi et reception de message
  //sendMessage("+33605537064","Test");
  ///initHttpGMS();
  readMessage();
  
  //2. Acceder et parser un sie web par connexion WiFi --> GET/POST
  //sendRequestByWiFi("Network","unefoisoui@1","http://rucher.polytech.unice.fr/~cpeter/exemple.html");
    /*Parameters:
      const char * ssid
      const char * password
      const String urlServer */
  //sendCommand("AT+CMGF=1");
  //3. Acceder et parser un sie web par LTE --> GET/POST
  //sendRequestByGSM("http://rucher.polytech.unice.fr/~cpeter/exemple.html");
  /*Parameters:
    const char * url
    Fontion principale d'envoie de la requete HTTP --> GET via GSM */
  
  //4. Trouver une location en parsant les satellites de localisation
  //satellite_GPS();
  
  
  //String a = "AT+CGNSPWR=1";// Activation de la communication
  //String b = "AT+CGNSINF"; // Fixation des donnees des Satellites*/
  //sendCommand(a,"toto",7000);


  //5. Principe
  /*Nous avons utiliser 100% la documentation
    pour implementer nos propres fonction sans passer par
    des bibliotheques. Ce qui rend nos codes puissants,
    personnalisable pour tout besoin et surtout tres rapide */

}
  //unsigned long startTime = millis();

 
void loop() {
 readByteSerial2();  //Pour les commandes AT
}

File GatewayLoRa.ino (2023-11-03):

#include "myFonctions.h"

void setup() {
  Serial.begin(9600);
  //myWiFiConnexion("Network", "unefoisoui@23");
  //sendRequestByWiFi("Network","unefoisoui@23","http://rucher.polytech.unice.fr/~cpeter/exemple.html");
  sendRequestByGSM("http://rucher.polytech.unice.fr/~cpeter/exemple.html");
  //initHttpGMS();
}

void loop() {
  readByteSerial2();  //Pour les commandes AT
  
}

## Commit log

2023-10-27 Add schematic v1
    [ESP_SIM7000V1.62.sch]
2023-10-27 Add brd file
    [ESP_SIM7000V1.62.brd]
2023-10-27 Ajout de la documentation
2023-11-03 Mise a jour de la fonction sendCommand
2023-11-27 Mise a jour du schematic du: 20/11/2023
2024-02-05 Fin du shematic et debut du routage
    [BOM_GatewayLoRa.csv, ESP_SIM7000V2.62.brd, ESP_SIM7000V2.62.sch]
2024-02-13 Ajout d'extraction de donnees GPS
2024-02-14 Correction schematic et ajout de TXB0108PWR
    [ESP_SIM7000V2.62.brd, ESP_SIM7000V2.62.sch]
2024-03-22 Ajout du GatewayLoRa - Design - All files
    [ESP_SIM7000V2.62.brd, ESP_SIM7000V2.62.sch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]

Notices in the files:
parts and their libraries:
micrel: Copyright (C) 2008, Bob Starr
